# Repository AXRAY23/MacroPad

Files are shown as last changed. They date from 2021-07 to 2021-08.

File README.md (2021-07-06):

# MacroPad
A collection of pcb and other files used in the creation of BedoDev's MacroPad.

# DISCLAIMER:
The libraries used for schematics and footprints are forked from other open source keyboard projects.
After I figure out how to use submodules i will remove them from the repo and create links to the original submodules from their respective git projects.

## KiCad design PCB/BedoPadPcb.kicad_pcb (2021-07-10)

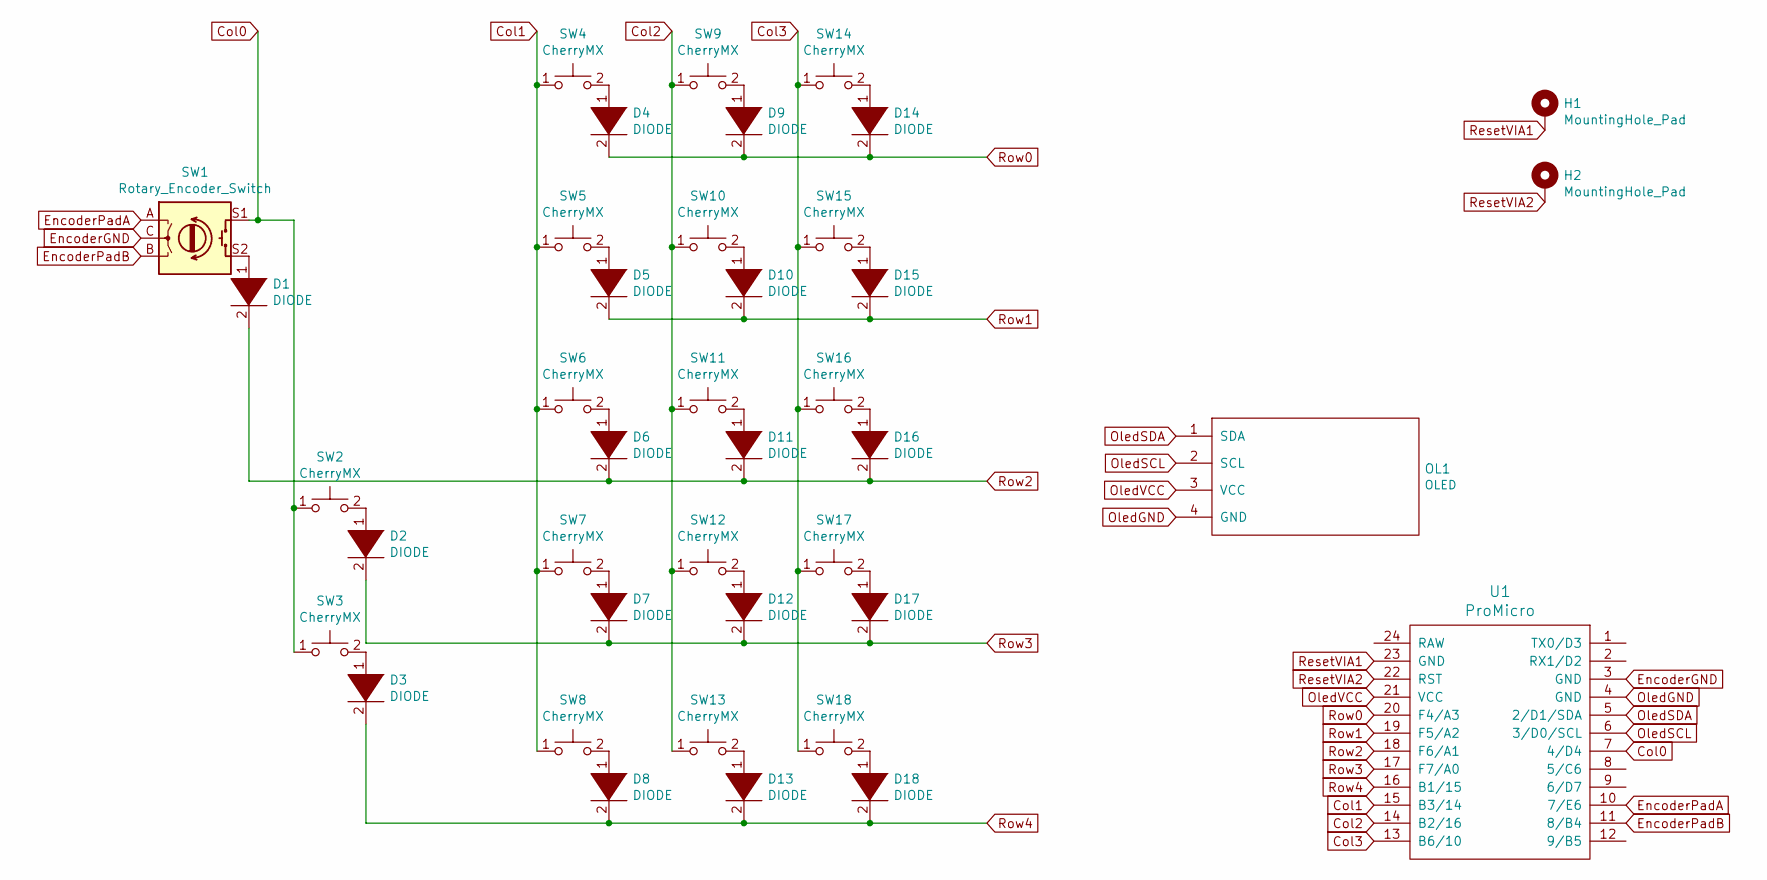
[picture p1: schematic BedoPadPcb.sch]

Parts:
D1, D2, D3, D4, D5, D6, D7, D8, D9, D10, D11, D12, D13, D14, D15, D16, D17, D18: DIODE; D3_TH
H1, H2: MountingHole_Pad; 1pin_conn
OL1: OLED; OLED_v2
SW1: Rotary_Encoder_Switch; RotaryEncoder_EC11
SW2, SW3, SW4, SW5, SW6, SW7, SW8, SW9, SW10, SW11, SW12, SW13, SW14, SW15, SW16, SW17, SW18: CherryMX; CherryMX_Hotswap
U1: ProMicro; ProMicro_v3

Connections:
Col0: SW1.S1, SW2.1, SW3.1, U1.7 (4/D4)
Col1: SW4.1, SW5.1, SW6.1, SW7.1, SW8.1, U1.15 (B3/14)
Col2: SW9.1, SW10.1, SW11.1, SW12.1, SW13.1, U1.14 (B2/16)
Col3: SW14.1, SW15.1, SW16.1, SW17.1, SW18.1, U1.13 (B6/10)
EncoderGND: SW1.C, U1.3 (GND)
EncoderPadA: SW1.A, U1.10 (7/E6)
EncoderPadB: SW1.B, U1.11 (8/B4)
unnamed: D1.1 (K), SW1.S2
unnamed: D2.1 (K), SW2.2
unnamed: D3.1 (K), SW3.2
unnamed: D4.1 (K), SW4.2
unnamed: D5.1 (K), SW5.2
unnamed: D6.1 (K), SW6.2
unnamed: D7.1 (K), SW7.2
unnamed: D8.1 (K), SW8.2
unnamed: D9.1 (K), SW9.2
unnamed: D10.1 (K), SW10.2
unnamed: D11.1 (K), SW11.2
unnamed: D12.1 (K), SW12.2
unnamed: D13.1 (K), SW13.2
unnamed: D14.1 (K), SW14.2
unnamed: D15.1 (K), SW15.2
unnamed: D16.1 (K), SW16.2
unnamed: D17.1 (K), SW17.2
unnamed: D18.1 (K), SW18.2
OledGND: OL1.4 (GND), U1.4 (GND)
OledSCL: OL1.2 (SCL), U1.6 (3/D0/SCL)
OledSDA: OL1.1 (SDA), U1.5 (2/D1/SDA)
OledVCC: OL1.3 (VCC), U1.21 (VCC)
ResetVIA1: H1.1, U1.23 (GND)
ResetVIA2: H2.1, U1.22 (RST)
Row0: D4.2 (A), D9.2 (A), D14.2 (A), U1.20 (F4/A3)
Row1: D5.2 (A), D10.2 (A), D15.2 (A), U1.19 (F5/A2)
Row2: D1.2 (A), D6.2 (A), D11.2 (A), D16.2 (A), U1.18 (F6/A1)
Row3: D2.2 (A), D7.2 (A), D12.2 (A), D17.2 (A), U1.17 (F7/A0)
Row4: D3.2 (A), D8.2 (A), D13.2 (A), D18.2 (A), U1.16 (B1/15)

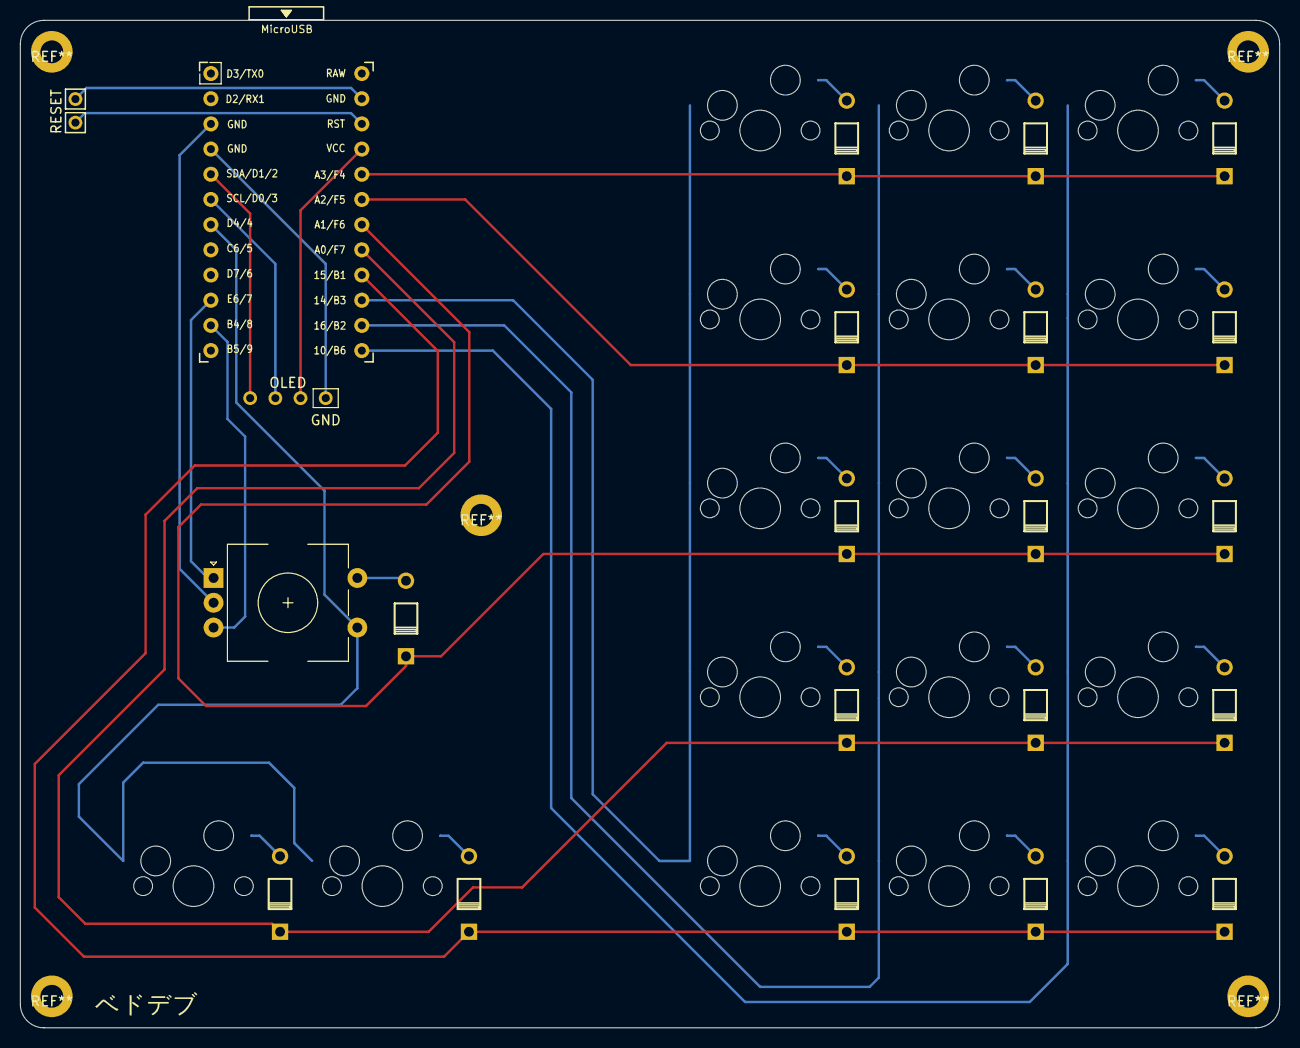
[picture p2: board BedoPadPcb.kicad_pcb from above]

Board: 2 copper layers, 127.0 x 101.6 mm, 40 parts (0 on the bottom side), 36 nets.

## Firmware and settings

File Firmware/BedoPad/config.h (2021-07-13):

/*
Copyright 2021 AXRAY23

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
You should have received a copy of the GNU General Public License
along with this program.  If not, see <http://www.gnu.org/licenses/>.
*/

#pragma once

#include "config_common.h"

/* USB Device descriptor parameter */
#define VENDOR_ID    0xBEED
#define PRODUCT_ID   0x0002
#define DEVICE_VER   0x0001
#define MANUFACTURER BedoDev
#define PRODUCT      BedoPad

/* key matrix size */
#define MATRIX_ROWS 5
#define MATRIX_COLS 4

/*
 * Keyboard Matrix Assignments
 *
 * Change this to how you wired your keyboard
 * COLS: AVR pins used for columns, left to right
 * ROWS: AVR pins used for rows, top to bottom
 * DIODE_DIRECTION: COL2ROW = COL = Anode (+), ROW = Cathode (-, marked on diode)
 *                  ROW2COL = ROW = Anode (+), COL = Cathode (-, marked on diode)
 *
 */
#define MATRIX_ROW_PINS { F4, F5, F6, F7, B1 }
#define MATRIX_COL_PINS { D4, B3, B2, B6 }
#define UNUSED_PINS

/* COL2ROW, ROW2COL */
#define DIODE_DIRECTION COL2ROW


#define ENCODERS_PAD_A { E6 }
#define ENCODERS_PAD_B { B4 }

#define ENCODER_RESOLUTION 4
#define TAP_CODE_DELAY 10

//#define LED_NUM_LOCK_PIN B0
//#define LED_CAPS_LOCK_PIN B1
//#define LED_SCROLL_LOCK_PIN B2
//#define LED_COMPOSE_PIN B3
//#define LED_KANA_PIN B4

//#define BACKLIGHT_PIN B7
//#define BACKLIGHT_LEVELS 3
//#define BACKLIGHT_BREATHING

//#define RGB_DI_PIN E2
//#ifdef RGB_DI_PIN
//#    define RGBLED_NUM 16
//#    define RGBLIGHT_HUE_STEP 8
//#    define RGBLIGHT_SAT_STEP 8
//#    define RGBLIGHT_VAL_STEP 8
//#    define RGBLIGHT_LIMIT_VAL 255 /* The maximum brightness level */
//#    define RGBLIGHT_SLEEP  /* If defined, the RGB lighting will be switched off when the host goes to sleep */
/*== all animations enable ==*/
//#    define RGBLIGHT_ANIMATIONS
/*== or choose animations ==*/
//#    define RGBLIGHT_EFFECT_BREATHING
//#    define RGBLIGHT_EFFECT_RAINBOW_MOOD
//#    define RGBLIGHT_EFFECT_RAINBOW_SWIRL
//#    define RGBLIGHT_EFFECT_SNAKE
//#    define RGBLIGHT_EFFECT_KNIGHT
//#    define RGBLIGHT_EFFECT_CHRISTMAS
//#    define RGBLIGHT_EFFECT_STATIC_GRADIENT
//#    define RGBLIGHT_EFFECT_RGB_TEST
//#    define RGBLIGHT_EFFECT_ALTERNATING
/*== customize breathing effect ==*/
/*==== (DEFAULT) use fixed table instead of exp() and sin() ====*/
//#    define RGBLIGHT_BREATHE_TABLE_SIZE 256      // 256(default) or 128 or 64
/*==== use exp() and sin() ====*/
//#    define RGBLIGHT_EFFECT_BREATHE_CENTER 1.85  // 1 to 2.7
//#    define RGBLIGHT_EFFECT_BREATHE_MAX    255   // 0 to 255
//#endif

/* Debounce reduces chatter (unintended double-presses) - set 0 if debouncing is not needed */
#define DEBOUNCE 5

/* define if matrix has ghost (lacks anti-ghosting diodes) */
//#define MATRIX_HAS_GHOST

/* Mechanical locking support. Use KC_LCAP, KC_LNUM or KC_LSCR instead in keymap */
#define LOCKING_SUPPORT_ENABLE
/* Locking resynchronize hack */
#define LOCKING_RESYNC_ENABLE

/* If defined, GRAVE_ESC will always act as ESC when CTRL is held.
 * This is useful for the Windows task manager shortcut (ctrl+shift+esc).
 */
//#define GRAVE_ESC_CTRL_OVERRIDE

/*
 * Force NKRO
 *
 * Force NKRO (nKey Rollover) to be enabled by default, regardless of the saved
 * state in the bootmagic EEPROM settings. (Note that NKRO must be enabled in the
 * makefile for this to work.)
 *
 * If forced on, NKRO can be disabled via magic key (default = LShift+RShift+N)
 * until the next keyboard reset.
 *
 * NKRO may prevent your keystrokes from being detected in the BIOS, but it is
 * fully operational during normal computer usage.
 *
 * For a less heavy-handed approach, enable NKRO via magic key (LShift+RShift+N)
 * or via bootmagic (hold SPACE+N while plugging in the keyboard). Once set by
 * bootmagic, NKRO mode will always be enabled until it is toggled again during a
 * power-up.
 *
 */
//#define FORCE_NKRO

/*
 * Feature disable options
 *  These options are also useful to firmware size reduction.
 */

/* disable debug print */
//#define NO_DEBUG

/* disable print */
//#define NO_PRINT

/* disable action features */
//#define NO_ACTION_LAYER
//#define NO_ACTION_TAPPING
//#define NO_ACTION_ONESHOT

/* disable these deprecated features by default */
#define NO_ACTION_MACRO
#define NO_ACTION_FUNCTION

/* Bootmagic Lite key configuration */
#define BOOTMAGIC_LITE_ROW 3
#define BOOTMAGIC_LITE_COLUMN 0

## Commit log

2021-07-06 Pcb layout finished
    [BedoPadPcb.sch]
2021-07-10 Final PCB
    [BedoPadPcb-B_Cu.gbr, BedoPadPcb-B_Mask.gbr, BedoPadPcb-B_SilkS.gbr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]
2021-07-13 Added plate svg file
2021-08-05 added finished plate
    [plate-maker-B_Cu.gbr, plate-maker-B_Mask.gbr, plate-maker-B_SilkS.gbr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]

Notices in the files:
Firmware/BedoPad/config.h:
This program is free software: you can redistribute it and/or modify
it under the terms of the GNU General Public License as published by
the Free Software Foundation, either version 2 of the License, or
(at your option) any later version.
